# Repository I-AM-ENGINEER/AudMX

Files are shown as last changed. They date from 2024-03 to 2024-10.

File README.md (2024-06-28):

# AudMX

Alternative for Deej ( https://github.com/omriharel/deej ) with more features

- Deej compatible
- RGB
- Looks cool
- Bluetooth
- Compact

Must be used with PC app for full features access ( https://github.com/Bobla-2/AudMx-win )

Russian language paper: https://habr.com/ru/sandbox/220106/

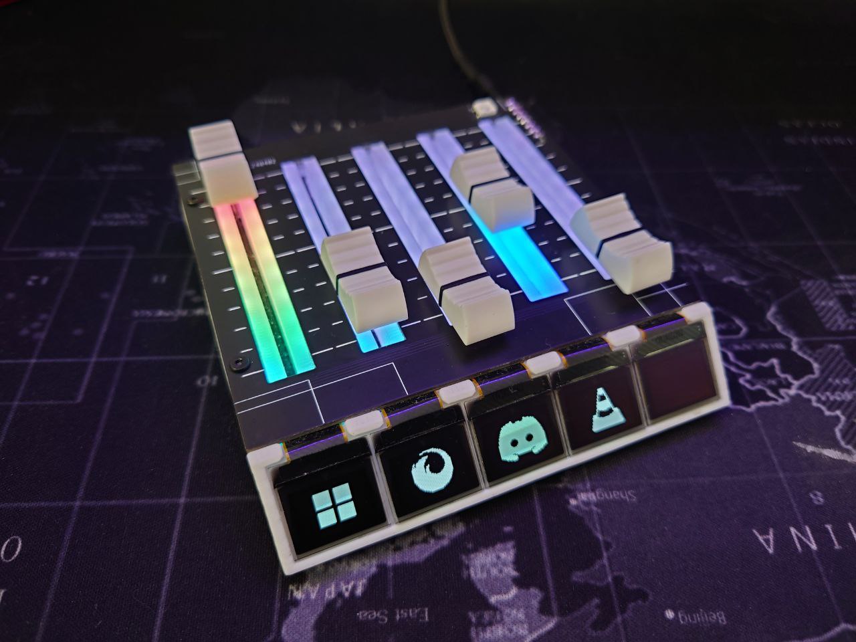
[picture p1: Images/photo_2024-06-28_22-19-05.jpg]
plot


plot

plot

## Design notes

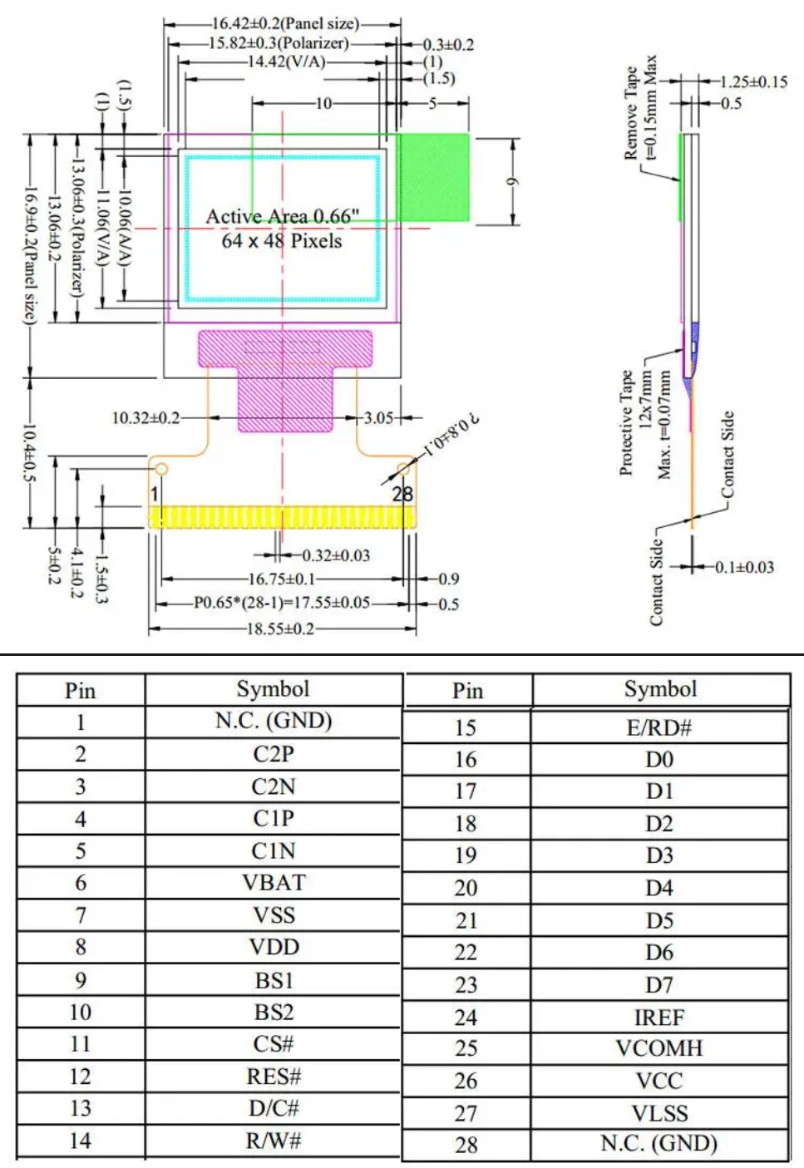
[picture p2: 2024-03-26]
Datasheets/0.66in SSD1315 display.png

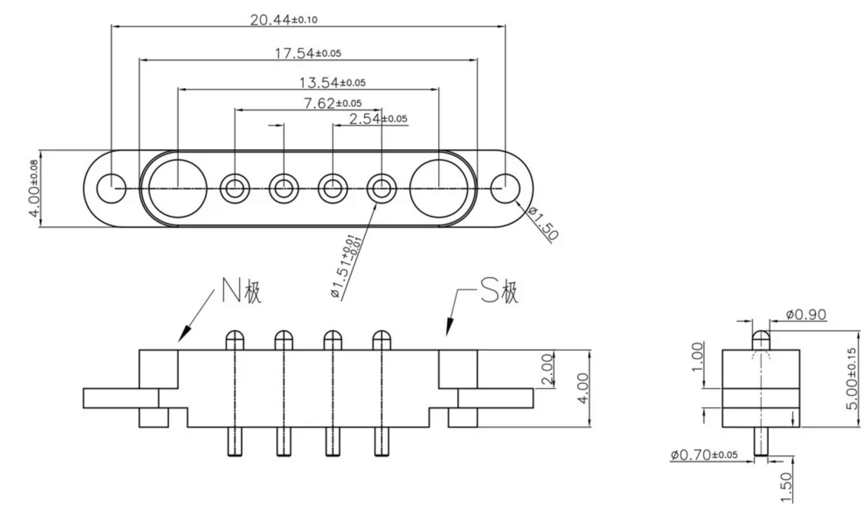
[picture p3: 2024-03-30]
Datasheets/4pin_pogo_1.png

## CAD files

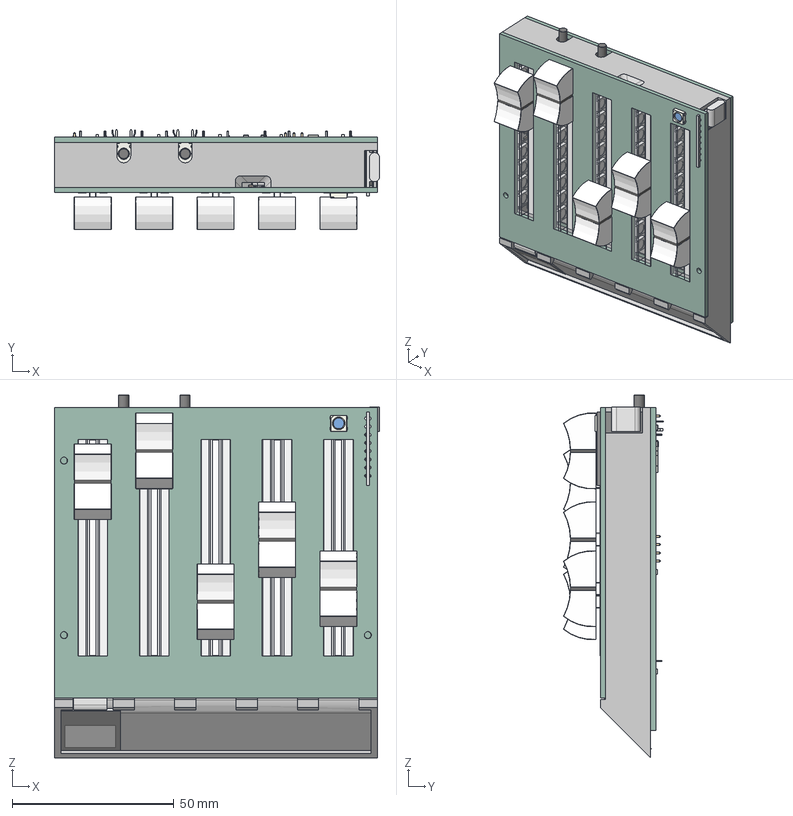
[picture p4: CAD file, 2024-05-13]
3dModels/STPs/AudMix-assembly.stp
100.7 x 30.9 x 112.3 mm
rp2040
Case
LED_WS2812B_PLCC4_50x50mm_P32mm
C_0603_1608Metric_1 x 38
R_0603_1608Metric_1 x 25
SOT_23_6
HSOP_8_1EP_39x49mm_P127mm_EP241x31mm
D_SOD_323
TSSOP_8_44x3mm_P065mm
SOT_223
AudMix_PCB
Connector1
Cup x 5
Slider x 5
Base144 x 100
Diffuser x 10
Brackets
0_42_oled
SW_Tactile_SPST_Angled_PTS645Vx83-2LFS_1 x 2
PinHeader_1x04_P254mm_Vertical
PinHeader_1x03_P254mm_Vertical
R_0603_1608Metric_3 x 11
C_0603_1608Metric_3 x 5
R_1206_3216Metric_1 x 5
AudMixBottom_PCB

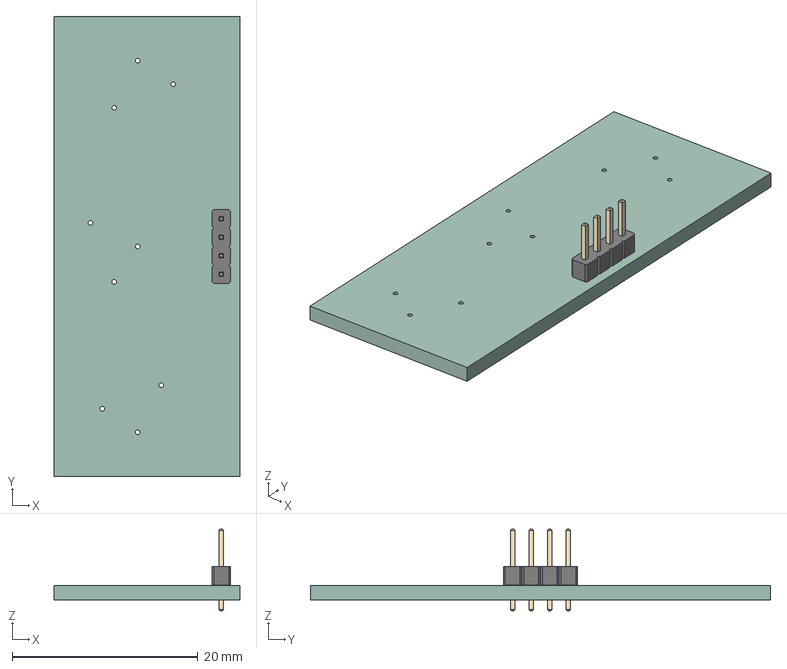
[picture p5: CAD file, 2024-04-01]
3dModels/PCBs/AudMixMacroPad.step
20.0 x 49.5 x 8.80 mm
PinHeader_1x04_P200mm_Vertical
AudMixMacroPad_PCB

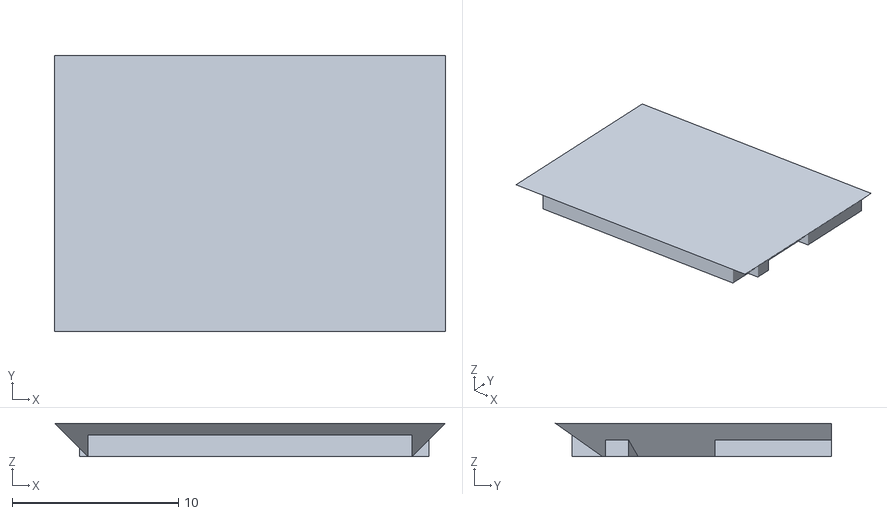
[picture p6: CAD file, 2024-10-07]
3dModels/STLs/ButtonPanelCup.stl
23.5 x 16.6 x 2.00

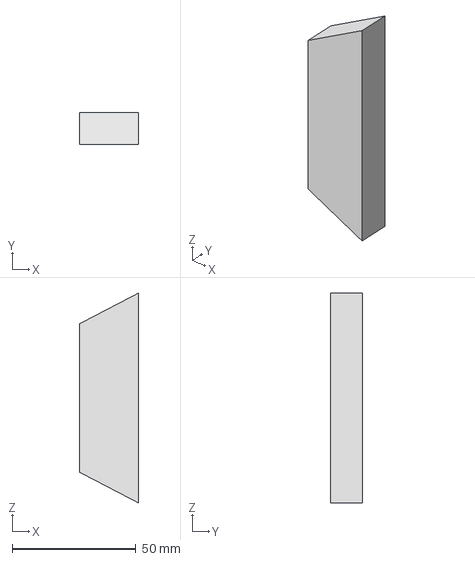
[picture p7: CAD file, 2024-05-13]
3dModels/STPs/ButtonPanel-example.stp
24.0 x 13.0 x 85.0 mm

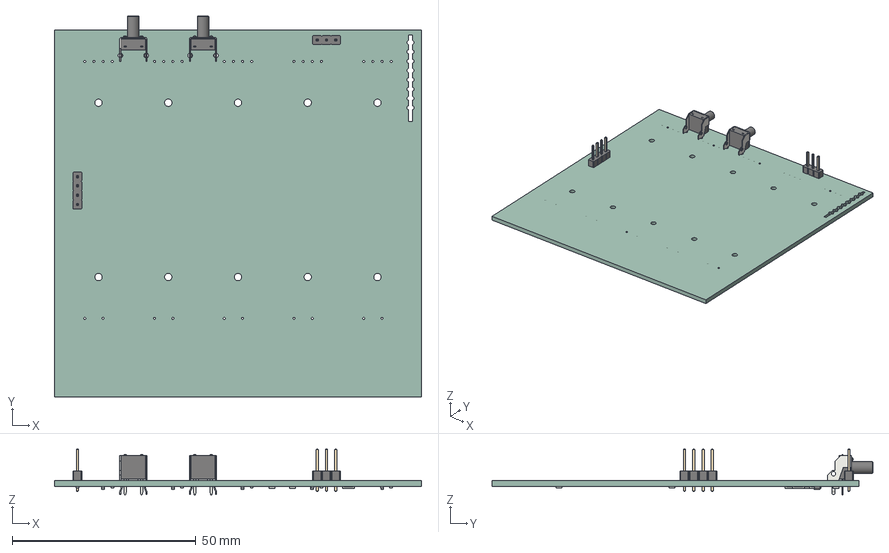
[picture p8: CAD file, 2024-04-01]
3dModels/PCBs/AudMixBottom.step
100.0 x 103.8 x 12.5 mm
SW_Tactile_SPST_Angled_PTS645Vx83-2LFS x 2
PinHeader_1x04_P254mm_Vertical
PinHeader_1x03_P254mm_Vertical
R_0603_1608Metric x 11
C_0603_1608Metric x 5
R_1206_3216Metric x 5
AudMixBottom_PCB

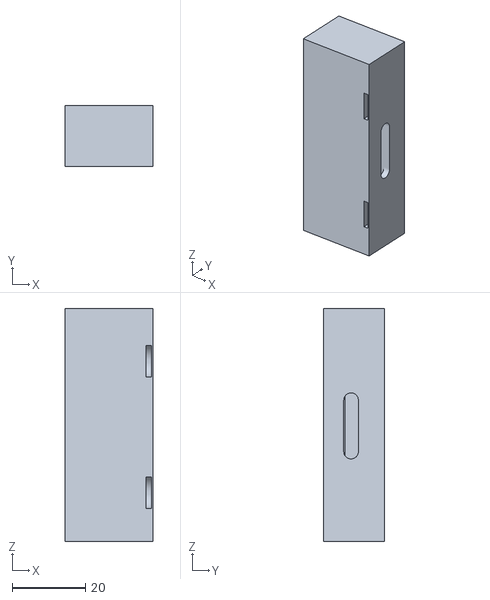
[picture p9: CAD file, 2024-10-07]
3dModels/STLs/ButtonPanelNew.stl
24.0 x 16.6 x 63.5

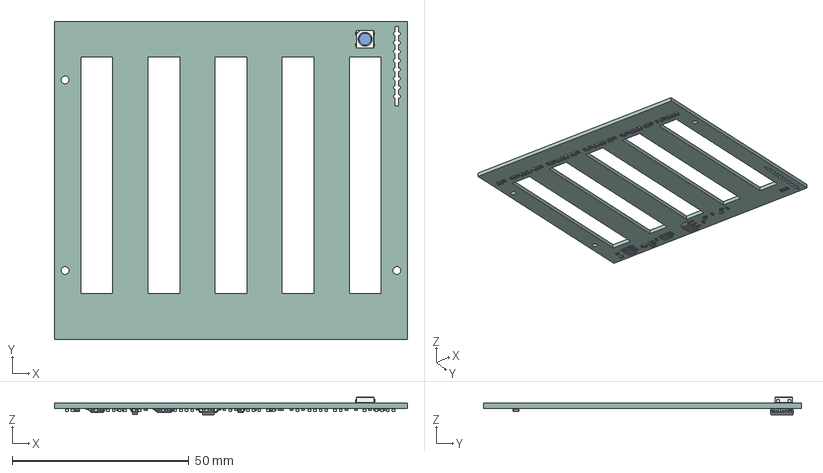
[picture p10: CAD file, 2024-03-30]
3dModels/PCBs/TopBoardPCB.step
100.0 x 90.0 x 5.00 mm
LED_WS2812B_PLCC4_50x50mm_P32mm
C_0603_1608Metric x 38
R_0603_1608Metric x 25
SOT_23_6
HSOP_8_1EP_39x49mm_P127mm_EP241x31mm
D_SOD_323
TSSOP_8_44x3mm_P065mm
SOT_223
AudMix_PCB

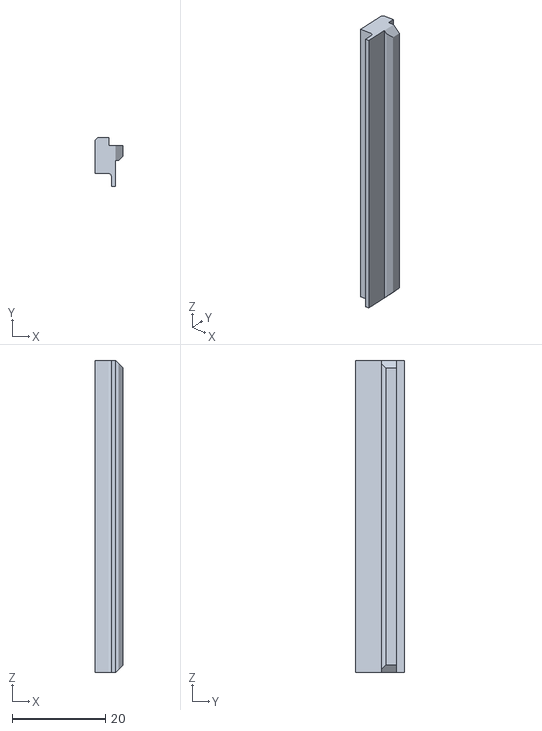
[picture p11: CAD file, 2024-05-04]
3dModels/STLs/Diffuser.stl
6.00 x 10.4 x 67.0

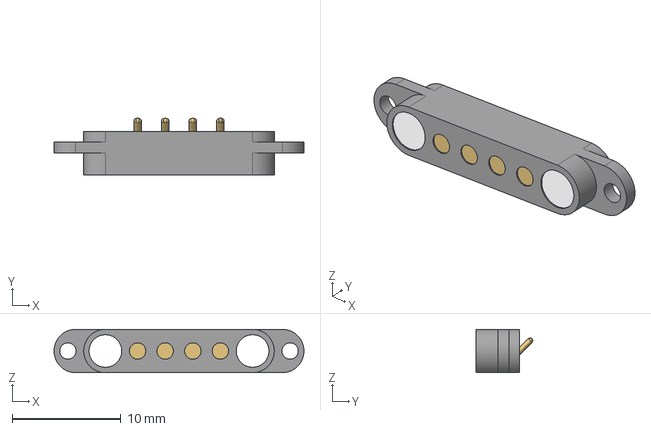
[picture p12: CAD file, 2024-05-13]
3dModels/STPs/Connector2.stp
23.0 x 5.20 x 4.00 mm

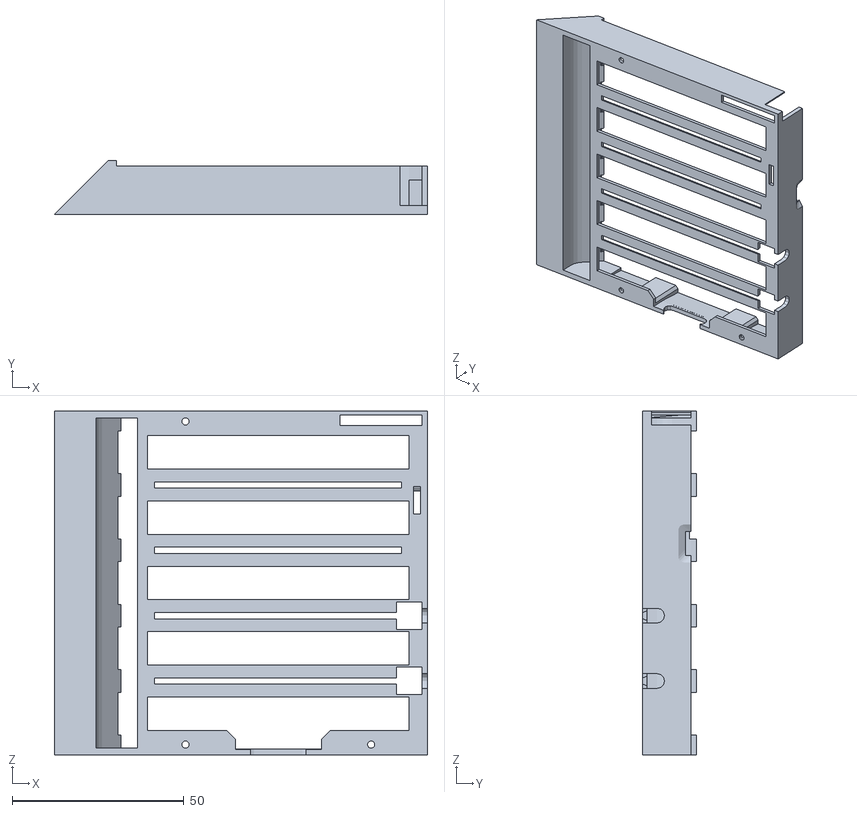
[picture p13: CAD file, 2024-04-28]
3dModels/STLs/Case.stl
108.5 x 15.6 x 100.0

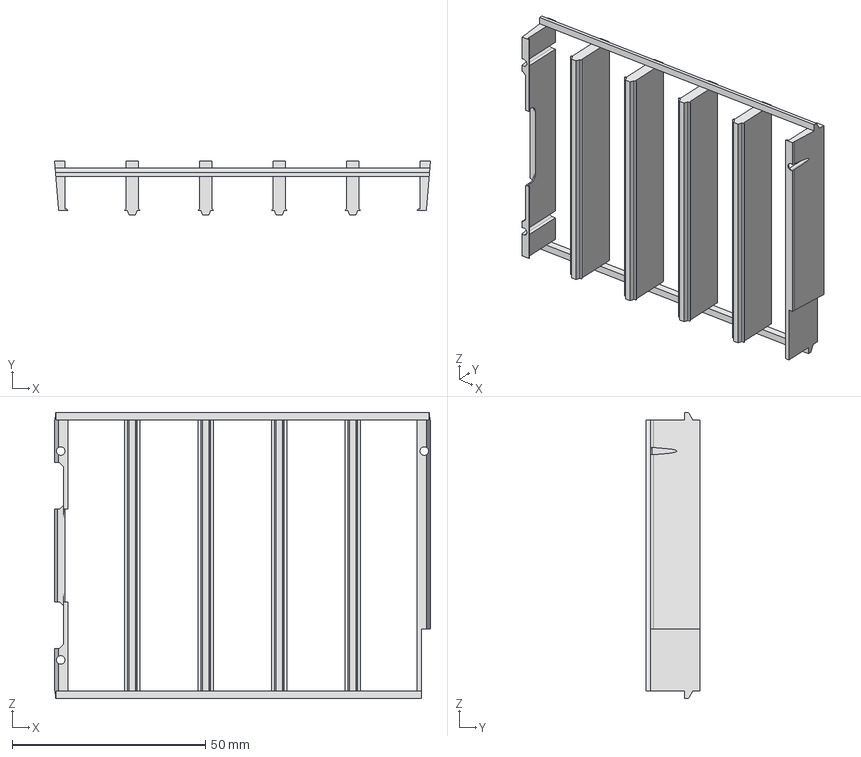
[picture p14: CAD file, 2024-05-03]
3dModels/STPs/Brackets.stp
97.2 x 14.0 x 74.0 mm

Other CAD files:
PCB/AudMixMacroPad/AudMixMacroPad.step
3dModels/0_69_oled.ipt
3dModels/Assembly.iam
3dModels/Bottom.ipt
3dModels/Brackets.ipt
3dModels/ButtonPanel.ipt
3dModels/ButtonPanelCup.ipt
3dModels/ButtonPanelNew.ipt
3dModels/Case.ipt
3dModels/Connector2.ipt
3dModels/Diffuser.ipt
3dModels/ESP32-super-micro.ipt
3dModels/Front.ipt
3dModels/LedStrip/144x10.iam
3dModels/LedStrip/Base144.ipt
3dModels/STLs/Brackets.stl
3dModels/Slider with leds.iam
3dModels/Slider/Body.ipt
3dModels/Slider/Cup.ipt
3dModels/Slider/Slider.ipt
3dModels/Slider/SliderAssembly.iam
3dModels/Sliders block.iam

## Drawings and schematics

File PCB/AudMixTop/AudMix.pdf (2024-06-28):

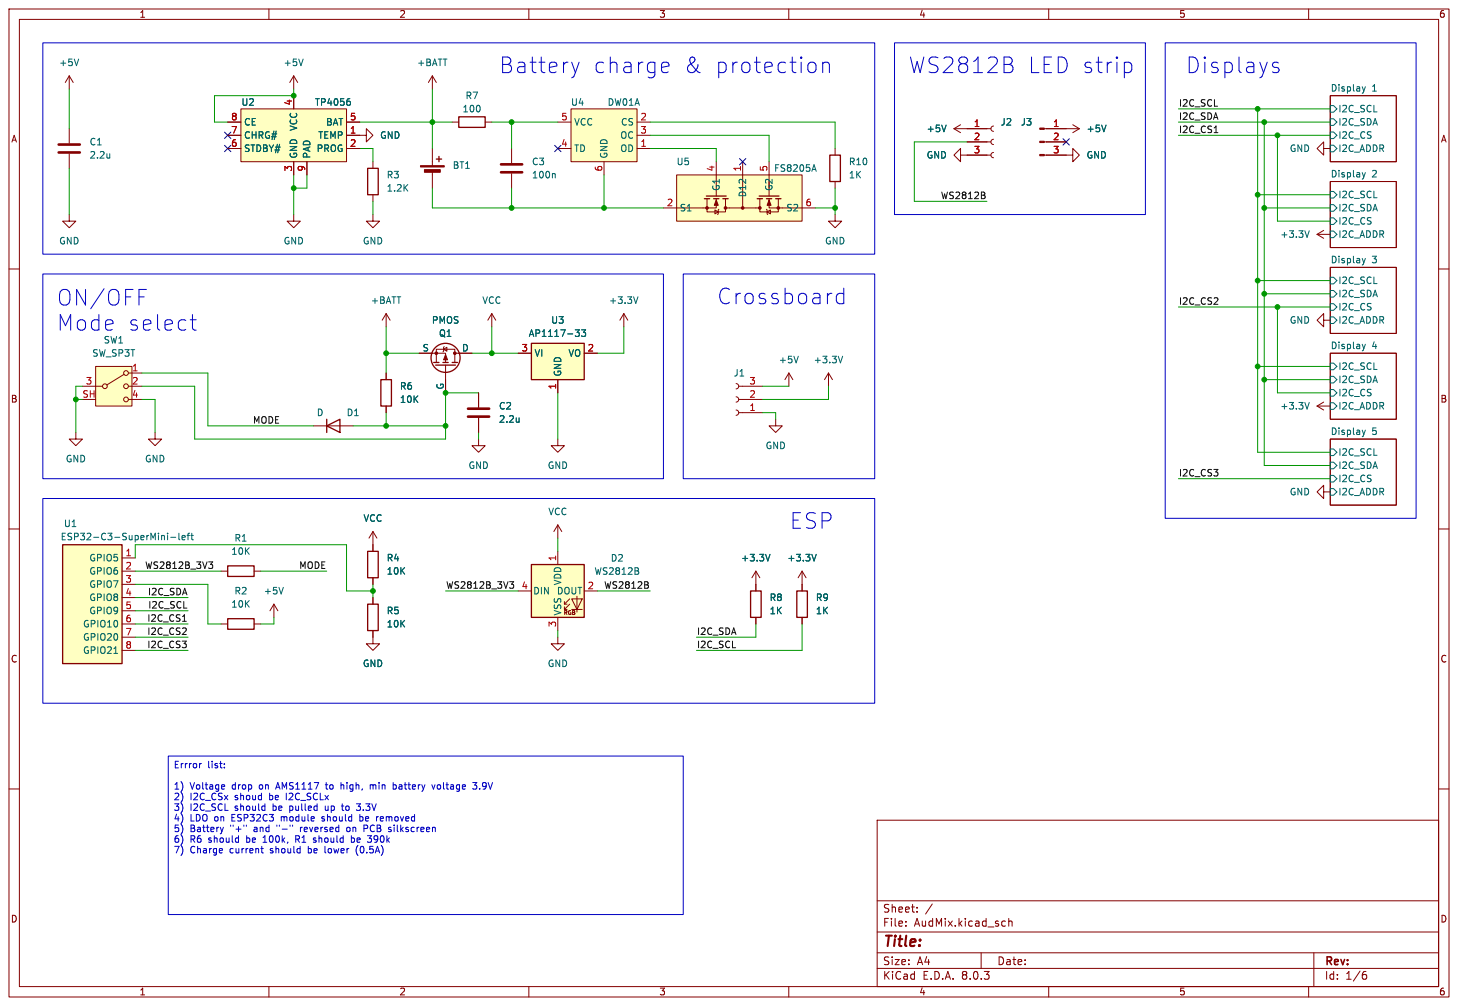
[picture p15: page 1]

4 BAT 5 STDBY# 6 CHRG# 7 CE 8 PAD

6) R6 should be 100k, R1 should be 390k 7) Charge current should be lower (0.5A)R4

Errror list: 1) Voltage drop on AMS1117 to high, min battery voltage 3.9V

2) I2C_CSx shoud be I2C_SCLx 3) I2C_SCL should be pulled up to 3.3V

4) LDO on ESP32C3 module should be removed

Id: 1/6 Title: File: AudMix.kicad_sch Sheet: /

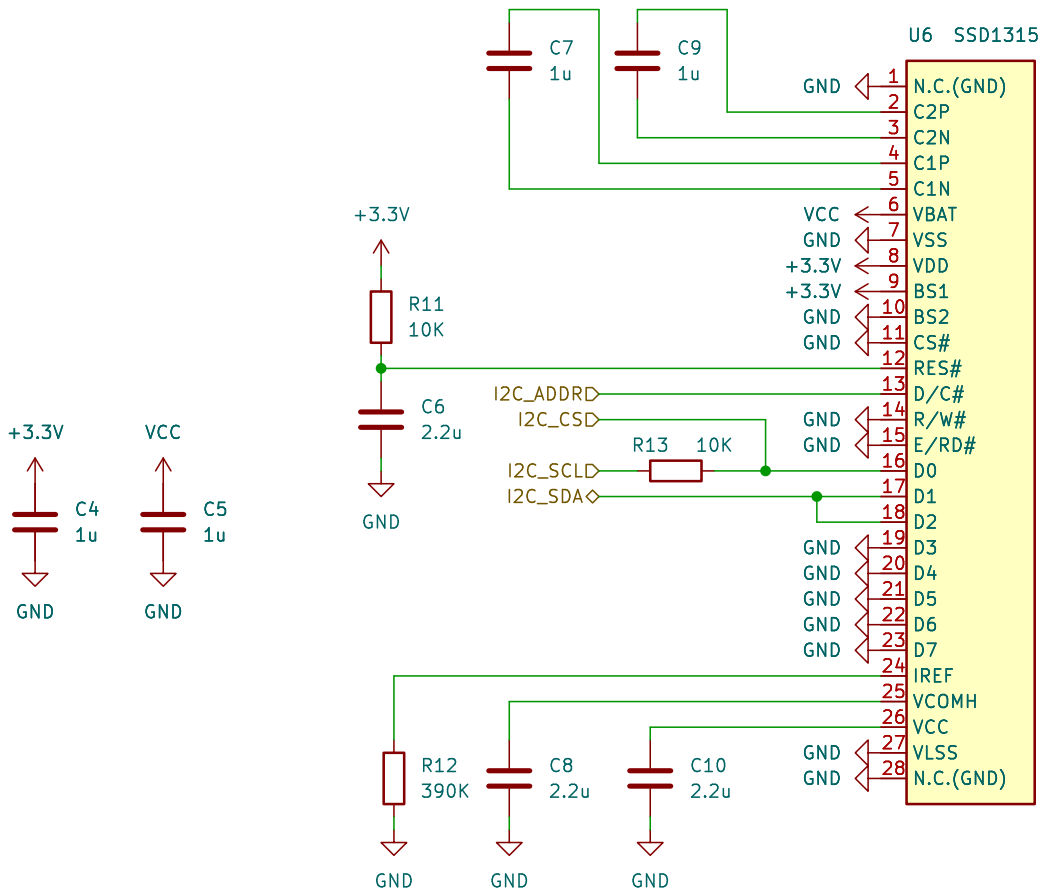
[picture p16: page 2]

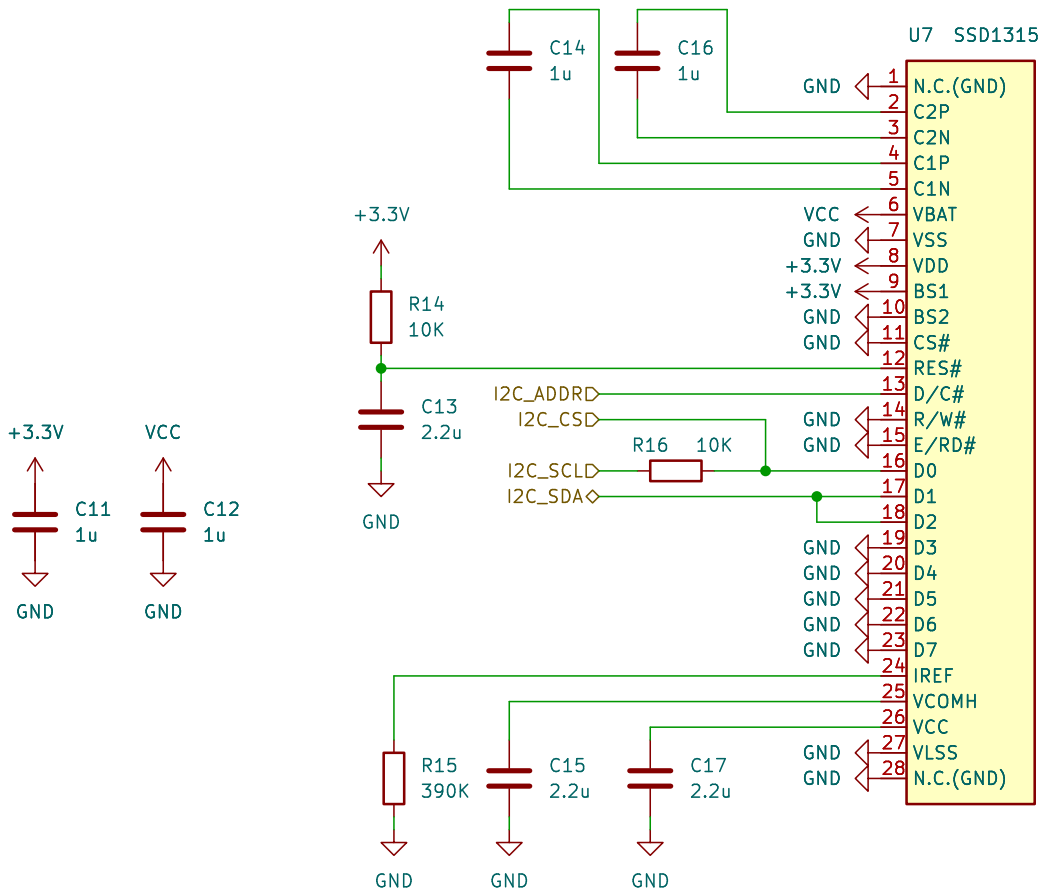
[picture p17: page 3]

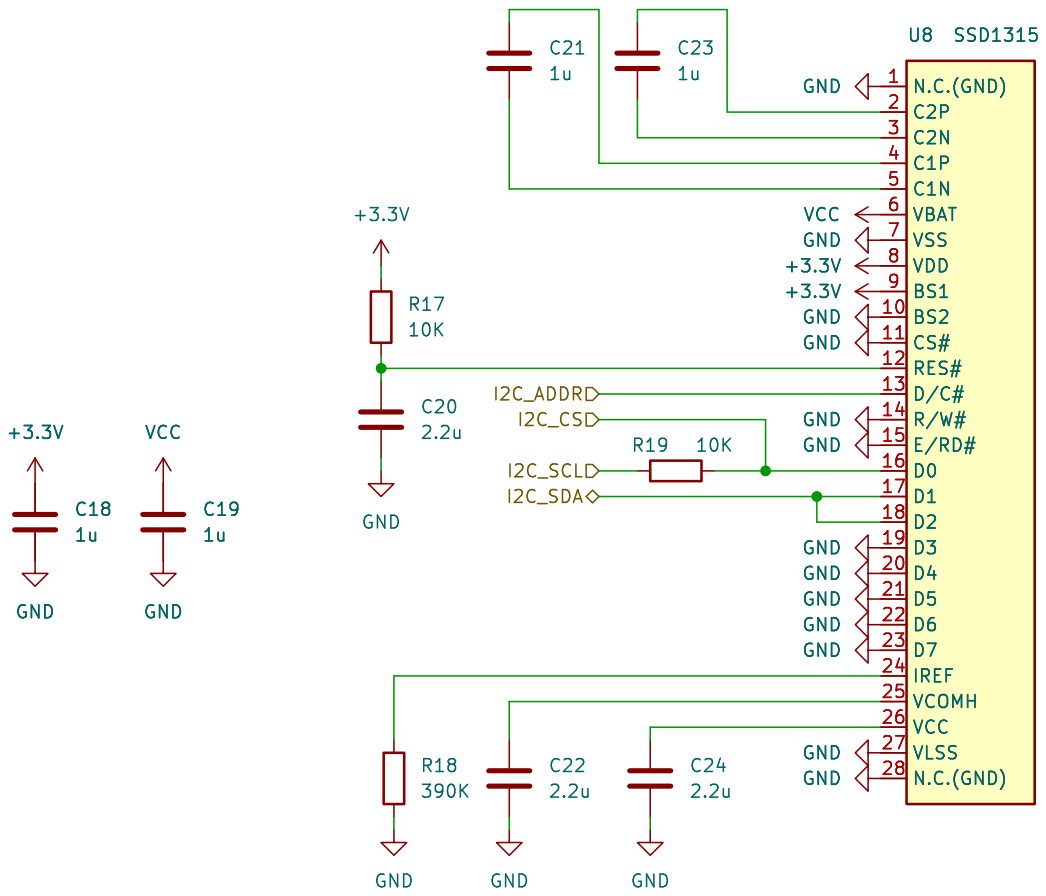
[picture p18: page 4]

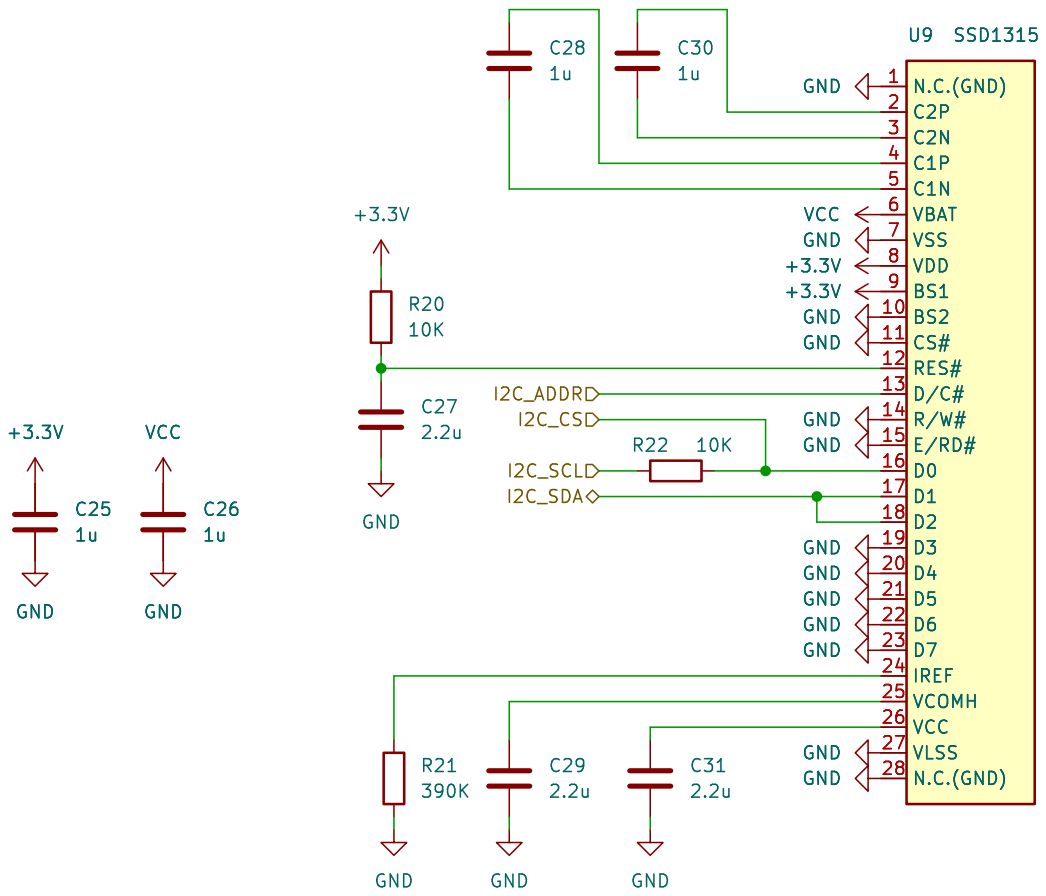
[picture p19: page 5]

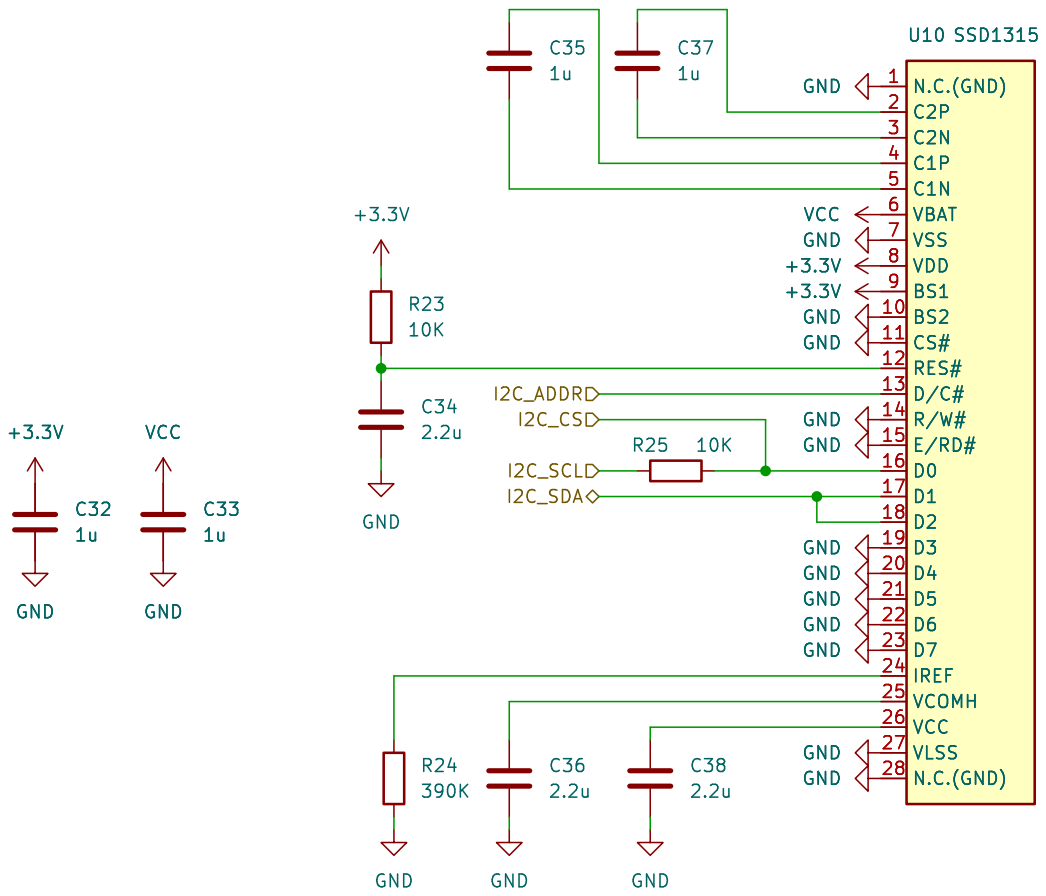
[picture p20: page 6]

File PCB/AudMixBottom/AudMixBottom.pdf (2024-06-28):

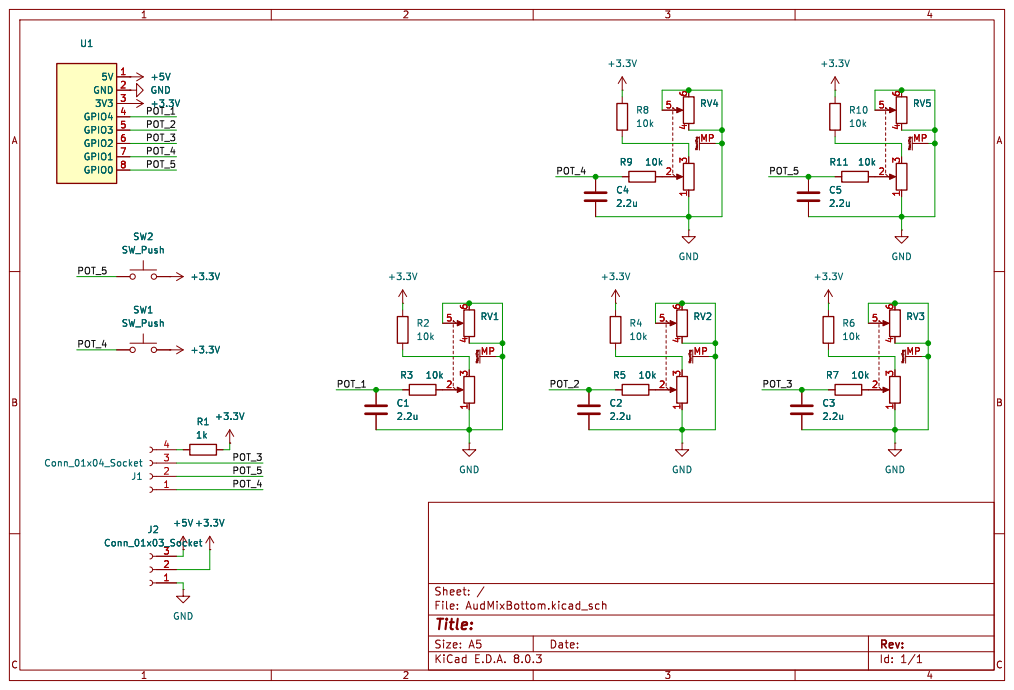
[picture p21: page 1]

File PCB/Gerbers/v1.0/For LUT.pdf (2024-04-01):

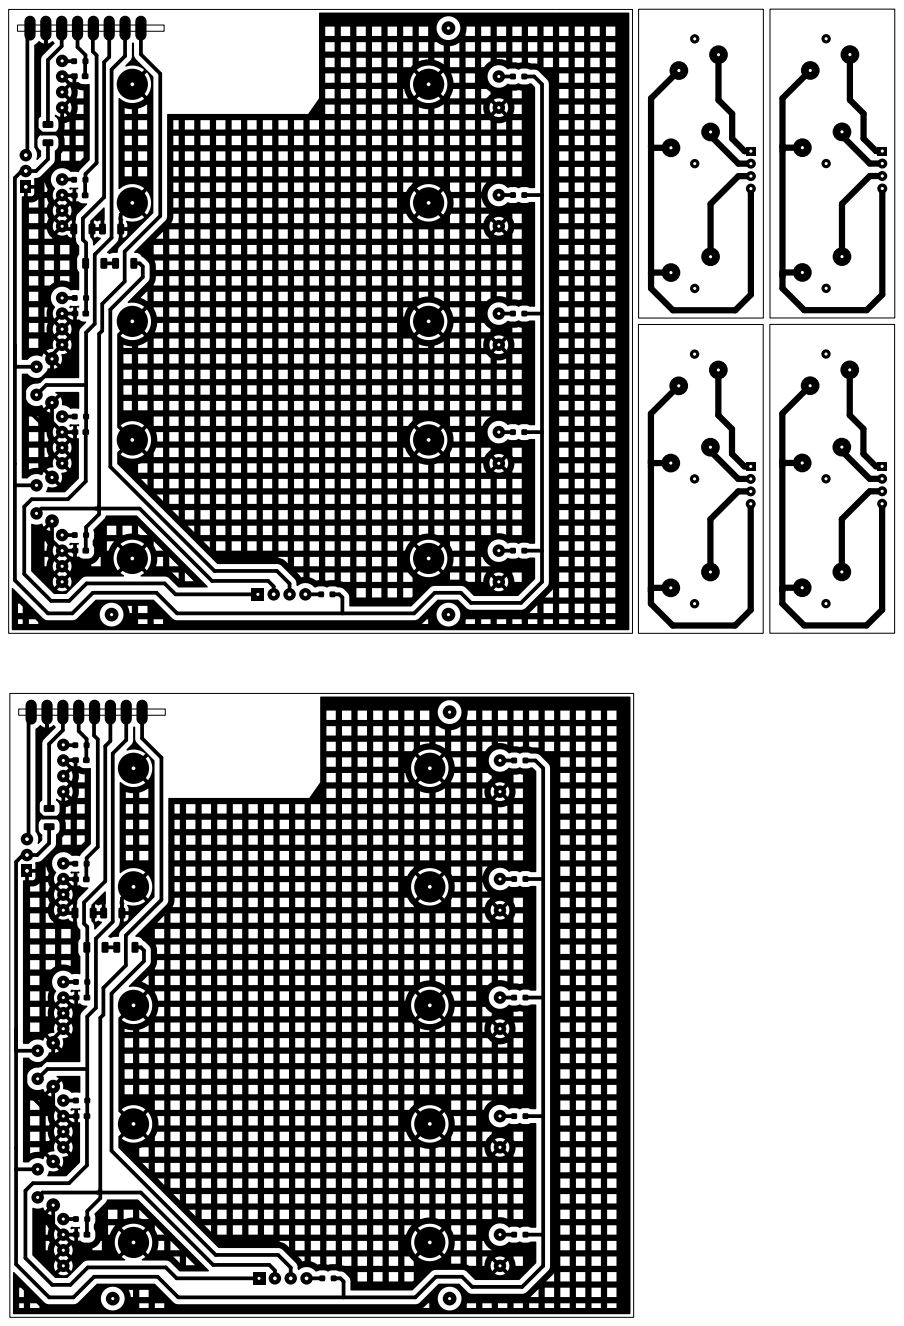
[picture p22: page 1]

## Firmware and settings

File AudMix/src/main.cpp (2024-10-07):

#include "esp_log.h"
#include "freertos/FreeRTOS.h"
#include "freertos/task.h"
#include "freertos/semphr.h"
#include "freertos/event_groups.h"
#include "device.hpp"
#include "displayTask.hpp"
#include "menuTask.hpp"
#include "sliderPosTask.hpp"
#include "animationTask.hpp"
#include "commTask.hpp"
#include "bt_spp.h"
#include "driver/spi_master.h"

extern "C" {
    void app_main(void);
}

extern CRGB *ws2812b_display_buffer;

static int64_t last_ping;

SemaphoreHandle_t displaysMutex;
EventGroupHandle_t buttonsPressedEventGroup;
EventGroupHandle_t buttonsReleasedEventGroup;

Device audMix; // I dont know, why i create class for entire device...

TaskHandle_t stripAnimationTaskHandle;
TaskHandle_t stripTaskHandle;
TaskHandle_t displayTaskHandle;
TaskHandle_t readPotentiometersButtonsTaskHandle;
TaskHandle_t menuTaskHandle;

void sleepTask( void *args );
void batteryCheckTask( void *args );

void app_main() {
    displaysMutex = xSemaphoreCreateMutex();
	buttonsPressedEventGroup = xEventGroupCreate();
	buttonsReleasedEventGroup = xEventGroupCreate();
    esp_log_level_set("*", ESP_LOG_NONE);
    //esp_log_level_set("NimBLE", ESP_LOG_INFO);

    audMix.init();

    ble_init();
    xTaskCreate(sleepTask, 		                    "sleepTask", 		3000, NULL, 1,  NULL);
    xTaskCreate(batteryCheckTask,                   "batteryTask", 	    1000, NULL, 2,  NULL);
    xTaskCreate(communicationTask,                  "consoleTask", 	    8000, NULL, 15, NULL);
    xTaskCreate(menuTask, 	                        "menuTask", 	    3000, NULL, 5,  &menuTaskHandle);
    xTaskCreate(stripAnimationTask,                 "stripAniTask", 	1000, NULL, 25, &stripAnimationTaskHandle);
    xTaskCreate(readPotentiometersButtonsTask, 		"analogTask", 		3000, NULL, 20, &readPotentiometersButtonsTaskHandle);
    xTaskCreate(displayTask,	                    "displaysTask", 	3000, NULL, 10, &displayTaskHandle);
    xTaskCreate(stripTask, 		                    "stripTask", 		3000, NULL, 30, &stripTaskHandle);
}

void batteryCheckTask( void *args ){
    gpio_config_t pin_cfg = {
        .pin_bit_mask = (1 << GPIO_NUM_7),
        .mode = GPIO_MODE_INPUT,
        .pull_down_en = GPIO_PULLDOWN_ENABLE,
    };
    gpio_config(&pin_cfg);
    
    while (1){
        float battery_level = audMix.battery.readLevel();
        bool low_charge = battery_level < 0.2;
        bool charger_connected = gpio_get_level(GPIO_NUM_7) == 1 ? true : false;
        if(low_charge && !charger_connected){
            ws2812b_display_buffer[0].r = 127;
            ws2812b_display_buffer[0].g = 0;
            ws2812b_display_buffer[0].b = 0;
            vTaskDelay(100);
        }
        ws2812b_display_buffer[0].r = 0;
        ws2812b_display_buffer[0].g = 0;
        ws2812b_display_buffer[0].b = 0;
        vTaskDelay(3000);
    }
}

void sleepPing( void ){
    last_ping = esp_timer_get_time();
}

void sleepTask( void *args ){
    sleepPing();
    while (1){
        int64_t current_time = esp_timer_get_time();
        if(ble_is_connected()){
            sleepPing();
        }
        if((current_time - last_ping) > 30'000'000){
            vTaskSuspend(menuTaskHandle);
            vTaskSuspend(readPotentiometersButtonsTaskHandle);
            vTaskSuspend(stripAnimationTaskHandle);
            vTaskSuspend(displayTaskHandle);
            for(uint32_t i = 0; i < SLIDERS_COUNT; i++){
                audMix.sliders[i].display.sleep();
            }
            for(uint32_t i = 0; i < STRIP_LED_COUNT; i++){
                ws2812b_display_buffer[i].r = 0;
                ws2812b_display_buffer[i].g = 0;
                ws2812b_display_buffer[i].b = 0;
            }
            vTaskDelay(pdMS_TO_TICKS(100));
            vTaskSuspend(stripTaskHandle);

            while((current_time - last_ping) > 30'000'000){
                if(ble_is_connected()){
                    sleepPing();
                }
                vTaskDelay(pdMS_TO_TICKS(100));
            }
            
            for(uint32_t i = 0; i < SLIDERS_COUNT; i++){
                audMix.sliders[i].display.wakeup();
            }
            
            vTaskResume(menuTaskHandle);
            vTaskResume(readPotentiometersButtonsTaskHandle);
            vTaskResume(stripAnimationTaskHandle);
            vTaskResume(displayTaskHandle);
            vTaskResume(stripTaskHandle);
        }
        vTaskDelay(pdMS_TO_TICKS(1000));
    }
}

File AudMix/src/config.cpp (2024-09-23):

#include "device.hpp"

extern CRGB *ws2812b_display_buffer;

void Device::configure( void ){
    // Long press button 0 and 1 during boot for start calibration
    _buttons_pressed_for_calibration[0] = true;
    _buttons_pressed_for_calibration[1] = true;

    _button_for_stip_config = 0;
    _button_for_bluetooth_config = 1;
    _button_next = 0;
    _button_select = 1;

    // Slider 1 config
    {
        auto cfg = sliders[0].config();
        cfg.adc_channel     = ADC_CHANNEL_0;
        cfg.i2c_addr        = 0x3C;
        cfg.pin_sda         = I2C_SDA_PIN;
        cfg.pin_scl         = 10;
        cfg.led_start       = 81;
        cfg.led_count       = 10;
        cfg.double_leds     = true;
        cfg.led_strip       = ws2812b_display_buffer;
        cfg.button_number   = -1; // -1 - system button, no send buttons events to PC, > 0 - sending if pressed
        sliders[0].config(cfg);
    }

    // Slider 2 config
    {
        auto cfg = sliders[1].config();
        cfg.adc_channel     = ADC_CHANNEL_1;
        cfg.i2c_addr        = 0x3D;
        cfg.pin_sda         = I2C_SDA_PIN;
        cfg.pin_scl         = 10;
        cfg.led_start       = 61;
        cfg.led_count       = 10;
        cfg.double_leds     = true;
        cfg.led_strip       = ws2812b_display_buffer;
        cfg.button_number   = -1;
        sliders[1].config(cfg);
    }

    // Slider 3 config
    {
        auto cfg = sliders[2].config();
        cfg.adc_channel     = ADC_CHANNEL_2;
        cfg.i2c_addr        = 0x3D;
        cfg.pin_sda         = I2C_SDA_PIN;
        cfg.pin_scl         = 20;
        cfg.led_start       = 41;
        cfg.led_count       = 10;
        cfg.double_leds     = true;
        cfg.led_strip       = ws2812b_display_buffer;
        cfg.button_number   = 0;
        sliders[2].config(cfg);
    }

    // Slider 4 config
    {
        auto cfg = sliders[3].config();
        cfg.adc_channel     = ADC_CHANNEL_3;
        cfg.i2c_addr        = 0x3C;
        cfg.pin_sda         = I2C_SDA_PIN;
        cfg.pin_scl         = 20;
        cfg.led_start       = 21;
        cfg.led_count       = 10;
        cfg.double_leds     = true;
        cfg.led_strip       = ws2812b_display_buffer;
        cfg.button_number   = 2;
        sliders[3].config(cfg);
    }

    // Slider 5 config
    {
        auto cfg = sliders[4].config();
        cfg.adc_channel     = ADC_CHANNEL_4;
        cfg.i2c_addr        = 0x3C;
        cfg.pin_sda         = I2C_SDA_PIN;
        cfg.pin_scl         = 21;
        cfg.led_start       = 1;
        cfg.led_count       = 10;
        cfg.double_leds     = true;
        cfg.led_strip       = ws2812b_display_buffer;
        cfg.button_number   = 1;
        sliders[4].config(cfg);
    }
}

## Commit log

2024-03-26 Top pcb
    [0_42_oled.ipt, 144x10.iam, Assembly.iam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]
2024-03-30 PCB production ready
    [Assembly.iam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]
2024-04-01 All PCBs complete
    [0_42_oled.ipt, 0_69_oled.ipt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]
2024-04-13 Slider calibration
2024-04-28 Something work
    [0_69_oled.ipt, 144x10.iam, Base144.ipt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]
2024-05-01 Worked led, first animation
    [Front.stl]
2024-05-02 Error list + slider led offset fix
    [AudMix.kicad_sch]
2024-05-02 Icon out + bugfix
    [device.cpp, main.cpp, slider.cpp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]
2024-05-03 Calibration process
    [Brackets.stp]
2024-05-03 Fully worked calibration
2024-05-04 Update diffuser
    [Body.ipt, Diffuser.ipt, Diffuser.stl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]
2024-05-04 Slider filter
2024-05-14 New buttons stack
    [Bottom.ipt]
2024-06-27 Battery check & discharge blink
2024-06-27 When charging no warn low battery
2024-06-28 Photos, schematic
2024-09-07 Buttons order fix
2024-10-07 Fix timeout & add button panel
    [ButtonPanelCup.ipt, ButtonPanelCup.stl, ButtonPanelNew.ipt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]
